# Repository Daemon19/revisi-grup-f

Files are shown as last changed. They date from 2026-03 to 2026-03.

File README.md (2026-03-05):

# 🤖 Revisi Grup F Bayucaraka

Repositori ini berisi hasil pengembangan dan revisi **Final Project Bayucaraka**, yang mencakup tiga bagian utama:

- ⚡ **Electrical**: desain PCB, skematik, dan firmware mikrokontroler.
- 🔧 **Mechanical**: model CAD komponen dan assembly.
- 💻 **Programming**: workspace pemrograman tambahan (MCU/ROS/script).

## 📝 Catatan

- Catatan revisi yang dilakukan dapat ditemukan pada README di masing-masing directory subdivisi
- Folder `Demo` menyimpan versi saat demo.
- Folder `Revisi` adalah hasil perbaikan akhir.

## 🎯 Tujuan Proyek

Proyek ini membangun sistem aktuator berbasis **ESP32** untuk mekanisme pemindahan objek (pick-and-place sederhana), dengan kombinasi:

- 🔀 2 sumbu gerak linear menggunakan motor stepper (X dan Y),
- 🎮 2 servo untuk mekanisme capit dan naik-turun,
- 🏠 limit switch sebagai referensi gerak/home.

## 📁 Struktur Folder Utama

- ⚡ `electrical/`
  - `Demo/`: versi awal desain dan kode.
  - `Revisi/`: versi perbaikan (PCB + firmware final revisi).
    - `CNC V4 Power Jack (PCB)/`: file KiCad (`.kicad_pcb`, `.kicad_sch`, dsb).
    - `FP BAYUCARAKA/`: proyek PlatformIO firmware ESP32.
- 🔧 `mechanical/`
  - `Demo/`: model mekanik sebelum revisi.
  - `Revisi/`: model mekanik setelah revisi.
- 💻 `programming/`
  - `Demo/`: folder pengembangan kode MCU/ROS/script.
  - `Revisi/`: folder lanjutan untuk revisi pemrograman.

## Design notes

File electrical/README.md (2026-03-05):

# ⚡ Revisi Electrical

## 🖨️ PCB

Polaritas kapsitor 100uF pada front.silkscreen terbalik, sehingga dibenarkan di versi revisi

## 💾 KODE

Capit tidak terbuka maksimal sesuai yang dibutuhkan, maka value lebih disesuaikan pada int buka di fungsi `void capit()`.

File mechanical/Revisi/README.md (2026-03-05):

# 🔧 Revisi Mechanical

Bagian-Bagian yang diubah:

- 🏗️ Ground support lebih ringan dengan topologi
- 🦾 Claw lebih kecil dengan akurasi yang relatif sama
- 📉 Hampir semua bagian dibuat lebih kecil / ringan
- 🔄 Penggerak mekanisme lazy tongs di ganti menjadi system pulley, sehingga mekanisme lazy tongs atau linkage hanya memastikan claw dapat naik turun dengan stabil. Dilakukan karena mekanisme sebelumnya mengacaukan Center of Gravity Claw.
- 🎮 Servo di atas menjadi servo 360
- ⚙️ Mounting claw dan mounting atas memiliki 4 lubang total untuk menyeimbangkan claw sehingga claw tidak miring.

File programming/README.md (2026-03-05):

# 💻 Revisi Programming

Adalah hal yang sulit untuk menemukan bug pada proses penggerakan menuju _payload_ tanpa melakukan trial, sehingga bug pada saat demo masih tidak ditemukan.

Meskipun demikian, masih ada ruang untuk mengembangkan basis kode, tepatnya pada node ROS2.
Adapun pengembangannya sebagai berikut.

## 📷 Node Camera

- Kegagalan membuka sumber video akan memunculkan error
- Mempublish koordinat pixel saat file homography tidak ditemukan

## 🎯 Node Detector

- Meningkatkan akurasi deteksi ArUco dengan pengaturan parameter dan preproses

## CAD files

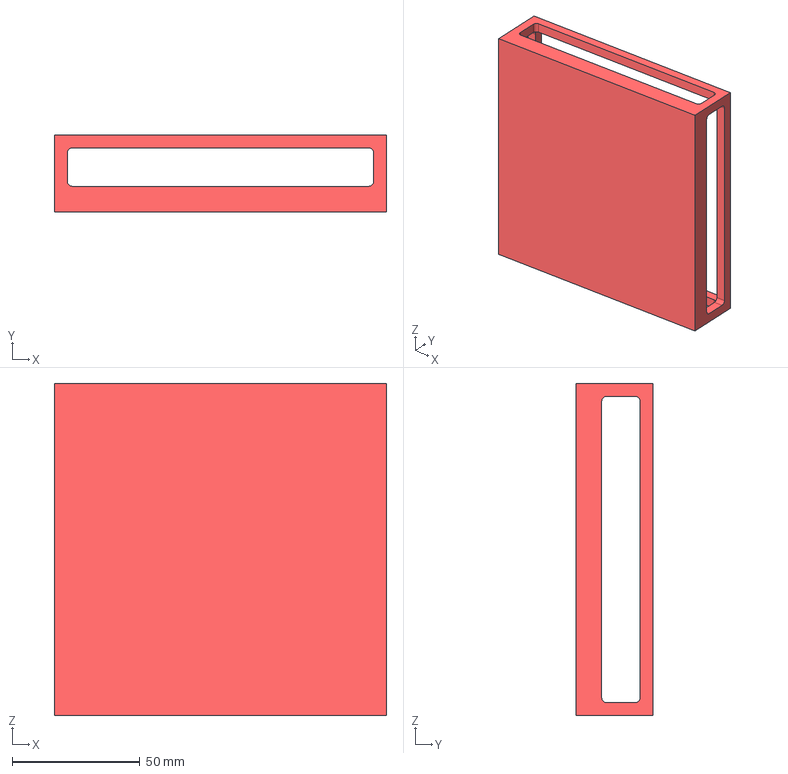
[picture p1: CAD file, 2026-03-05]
mechanical/Demo/Copy of Ground support (Sebelum Revisi).stp
130.0 x 30.0 x 130.0 mm

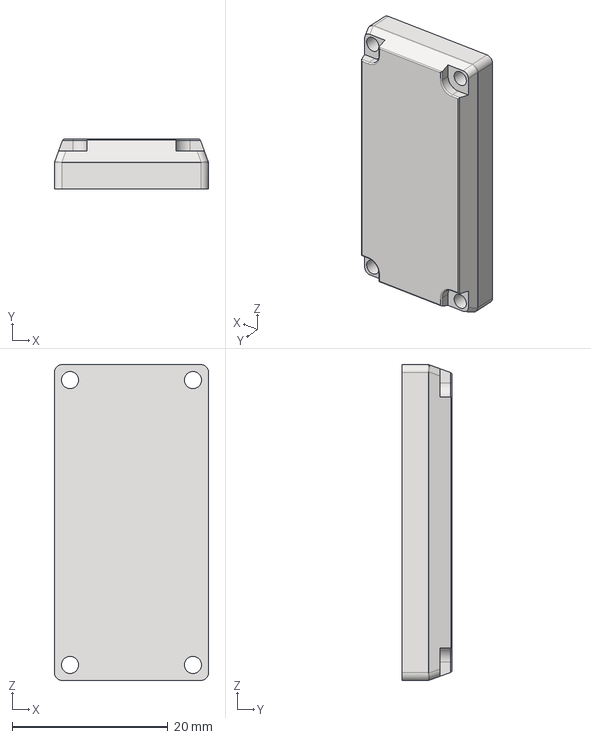
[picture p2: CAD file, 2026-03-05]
mechanical/Demo/FP (Sebelum Revisi)/Base.stp
19.8 x 6.40 x 40.6 mm

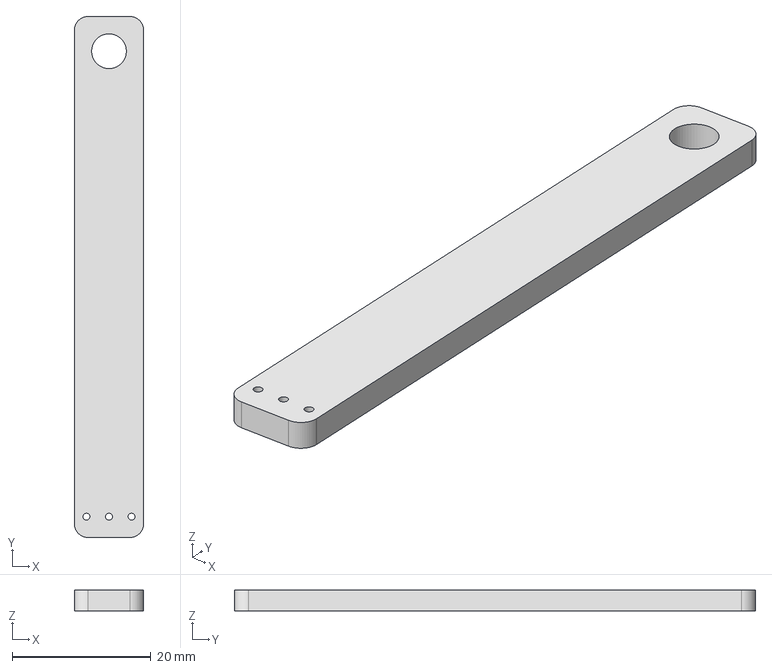
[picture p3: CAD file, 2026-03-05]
mechanical/Demo/FP (Sebelum Revisi)/Servo/FP V2 Servo Arm.stp
10.0 x 75.0 x 3.00 mm

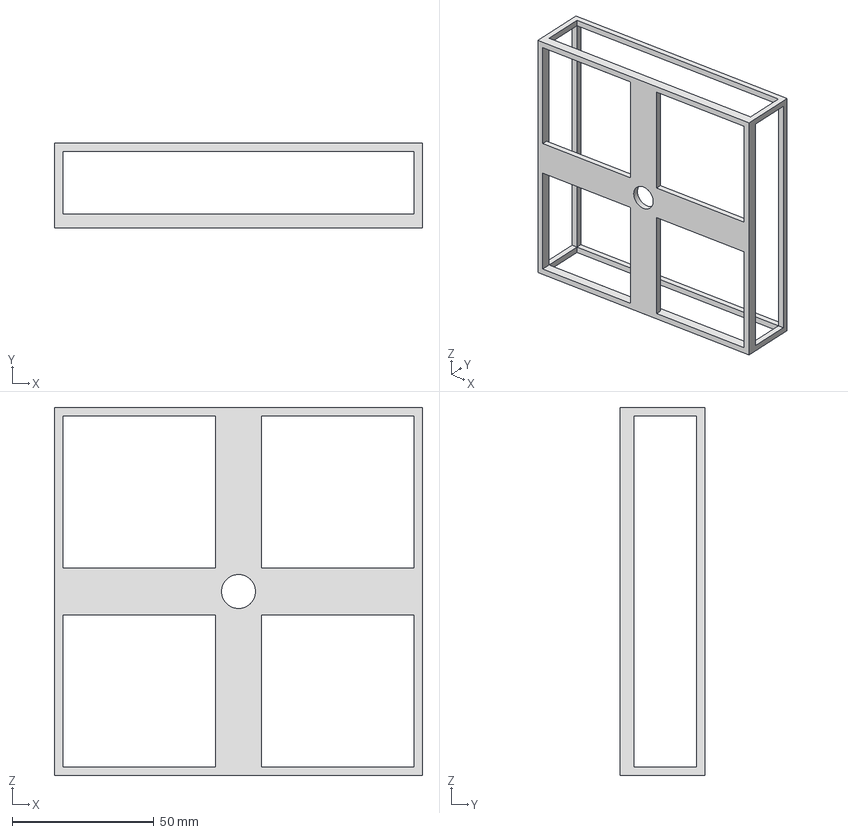
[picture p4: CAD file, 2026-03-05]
mechanical/Revisi/Ground Support (Topologi).stp
130.0 x 30.0 x 130.0 mm

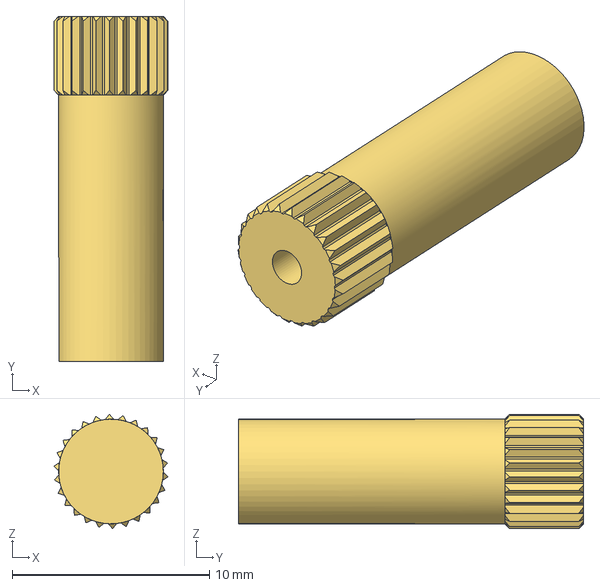
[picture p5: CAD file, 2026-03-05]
mechanical/Demo/FP (Sebelum Revisi)/Eje.stp
5.78 x 17.5 x 5.80 mm

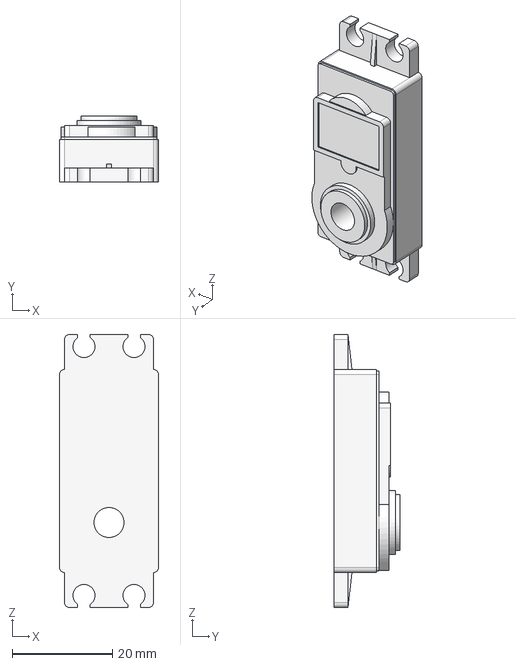
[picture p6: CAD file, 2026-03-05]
mechanical/Demo/FP (Sebelum Revisi)/Servo/Top.stp
19.8 x 13.2 x 54.6 mm

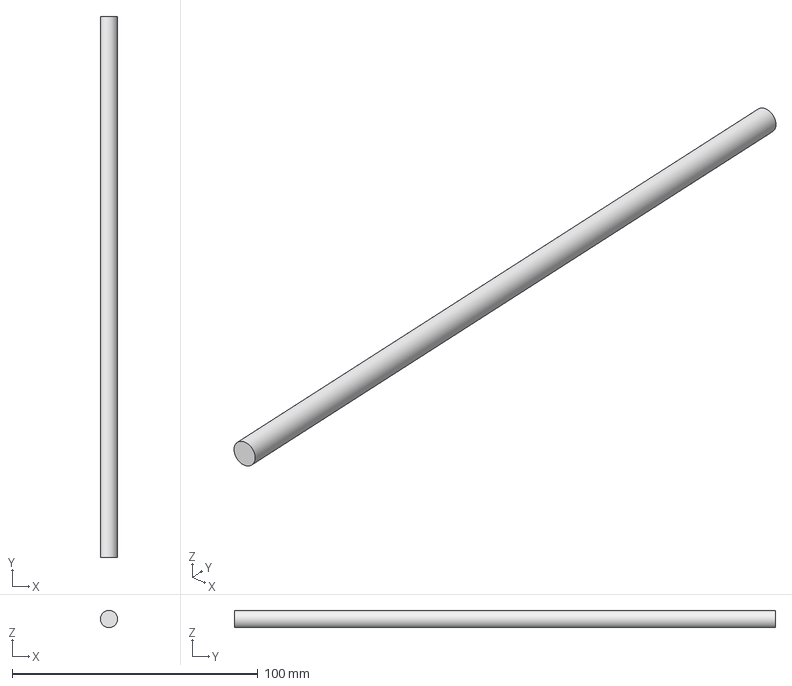
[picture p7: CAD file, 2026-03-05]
mechanical/Demo/FP (Sebelum Revisi)/FP V2 Spring Beam connector.stp
6.99 x 220.0 x 7.00 mm

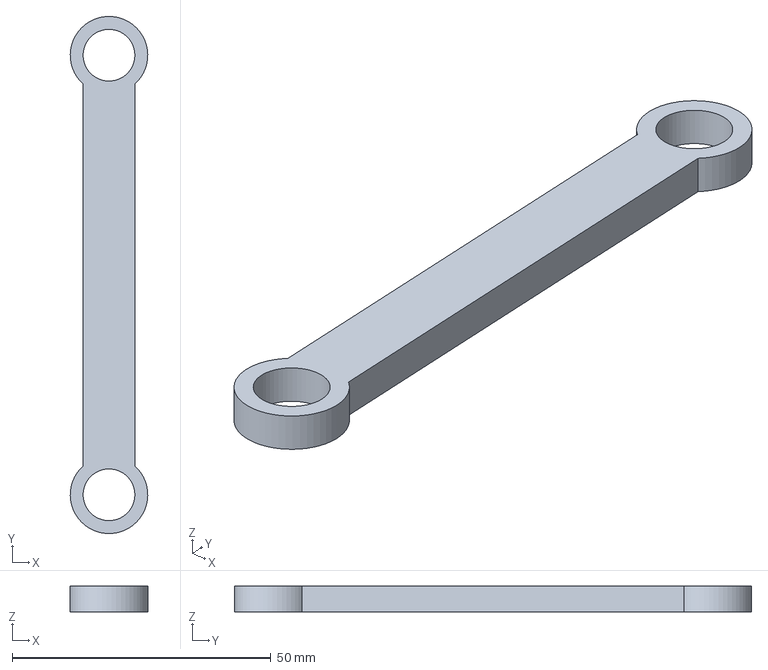
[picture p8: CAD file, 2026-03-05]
mechanical/Demo/FP (Sebelum Revisi)/FP V2 Lengan Serok.stp
15.0 x 100.0 x 5.00 mm

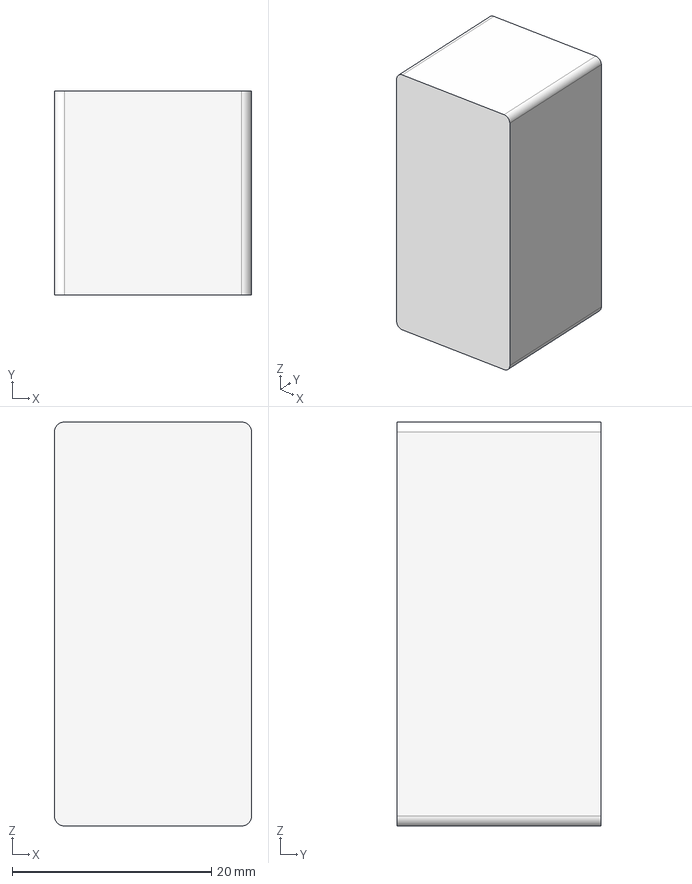
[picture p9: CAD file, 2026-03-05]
mechanical/Demo/FP (Sebelum Revisi)/Medio.stp
19.8 x 20.5 x 40.6 mm

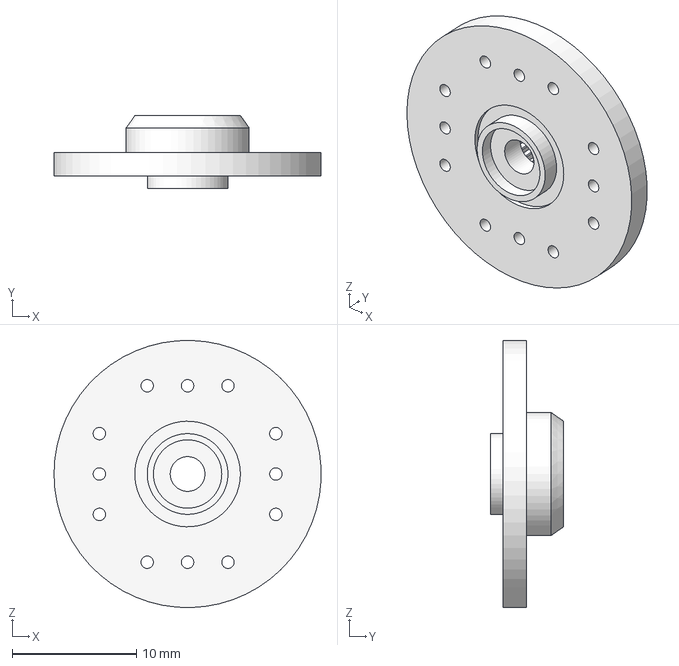
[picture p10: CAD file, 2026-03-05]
mechanical/Demo/FP (Sebelum Revisi)/Servo/Acople circular.stp
21.5 x 5.90 x 21.5 mm

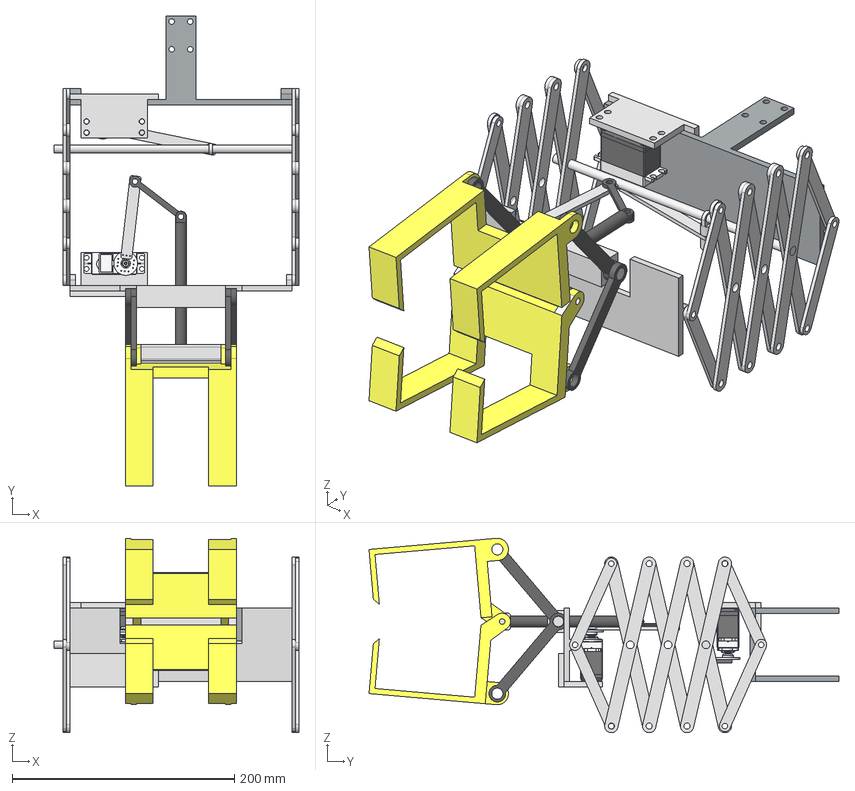
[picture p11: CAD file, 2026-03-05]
mechanical/Demo/FP (Sebelum Revisi)/Final Project Assem.stp
220.0 x 422.8 x 174.9 mm
FP V2 Claw Connector
FP V2 Shaft
FP V2 Arm Connector
FP V2 Mounting Claw
FP V2 Spring beam Short x 8
FP V2 Spring Beam x 12
FP V2 Mounting Plate
FP V2 Z Axis connector
FP V2 Spring Beam connector
fp v2 servo Mounting x 2
Top x 2
Medio x 2
Base x 2
Eje x 2
Acople circular x 2
FP V2 Servo Arm
FP V2 Batang Penggerak
FP V2 Servo Arm v2
FP V2 Claw
FP V2 Claw_Side
FP V2 Lengan Serok x 4

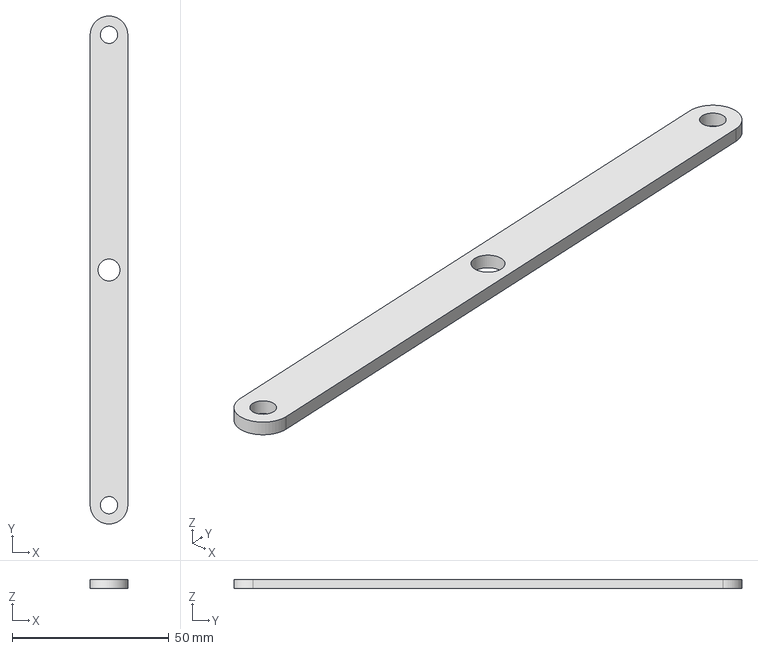
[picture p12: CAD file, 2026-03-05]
mechanical/Demo/FP (Sebelum Revisi)/FP V2 Spring Beam.stp
12.0 x 162.0 x 3.00 mm

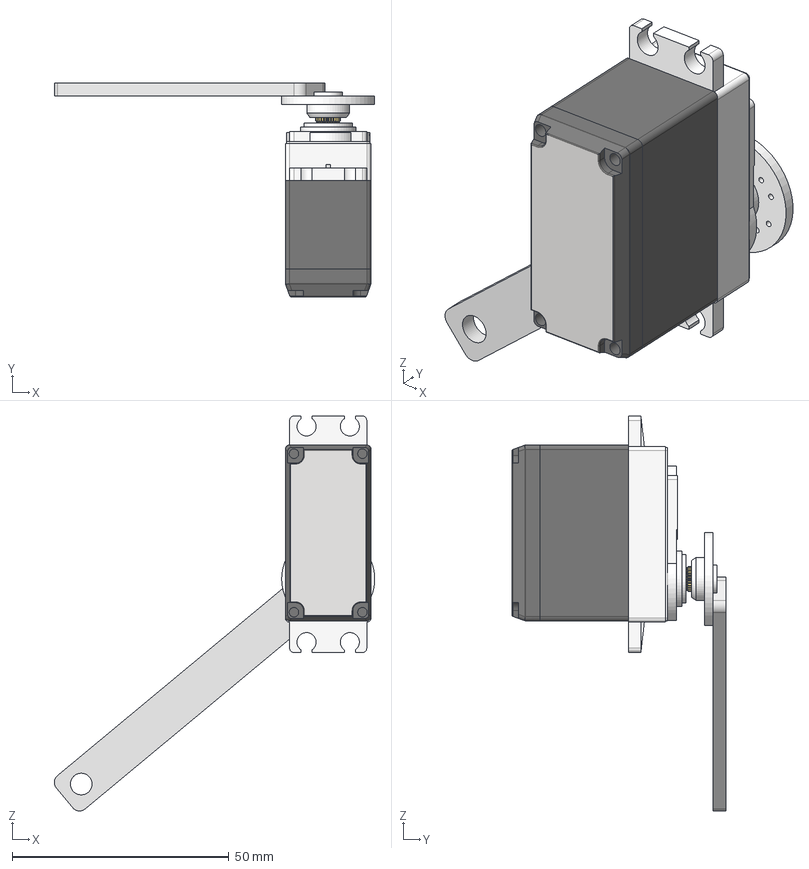
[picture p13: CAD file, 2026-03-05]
mechanical/Demo/FP (Sebelum Revisi)/Servo/MG_996R.stp
74.0 x 49.3 x 91.2 mm
Top
Medio
Base
Eje
Acople circular
FP V2 Servo Arm

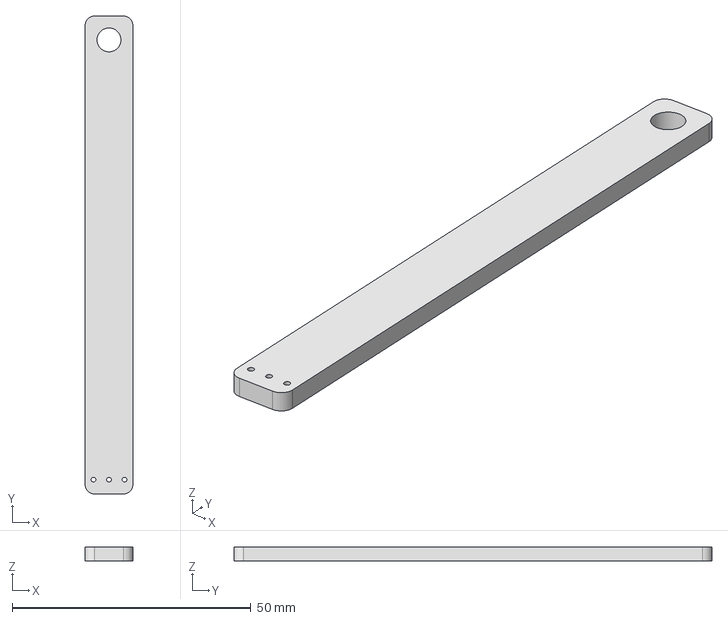
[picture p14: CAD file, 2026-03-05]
mechanical/Demo/FP (Sebelum Revisi)/Servo/FP V2 Servo Arm v2.stp
10.0 x 100.0 x 3.00 mm

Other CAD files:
mechanical/Demo/Copy of Ground Support (Sebelum Revisi).ipt
mechanical/Demo/FP (Sebelum Revisi)/Acople circular.ipt
mechanical/Demo/FP (Sebelum Revisi)/Base.ipt
mechanical/Demo/FP (Sebelum Revisi)/Eje.ipt
mechanical/Demo/FP (Sebelum Revisi)/FP V2 Arm Connector.ipt
mechanical/Demo/FP (Sebelum Revisi)/FP V2 Arm Connector.stp
mechanical/Demo/FP (Sebelum Revisi)/FP V2 Batang Penggerak.ipt
mechanical/Demo/FP (Sebelum Revisi)/FP V2 Batang Penggerak.stp
mechanical/Demo/FP (Sebelum Revisi)/FP V2 Claw Connector.ipt
mechanical/Demo/FP (Sebelum Revisi)/FP V2 Claw Connector.stp
mechanical/Demo/FP (Sebelum Revisi)/FP V2 Claw.ipt
mechanical/Demo/FP (Sebelum Revisi)/FP V2 Claw.stp
mechanical/Demo/FP (Sebelum Revisi)/FP V2 Claw_Side.ipt
mechanical/Demo/FP (Sebelum Revisi)/FP V2 Claw_Side.stp
mechanical/Demo/FP (Sebelum Revisi)/FP V2 Lengan Serok.ipt
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

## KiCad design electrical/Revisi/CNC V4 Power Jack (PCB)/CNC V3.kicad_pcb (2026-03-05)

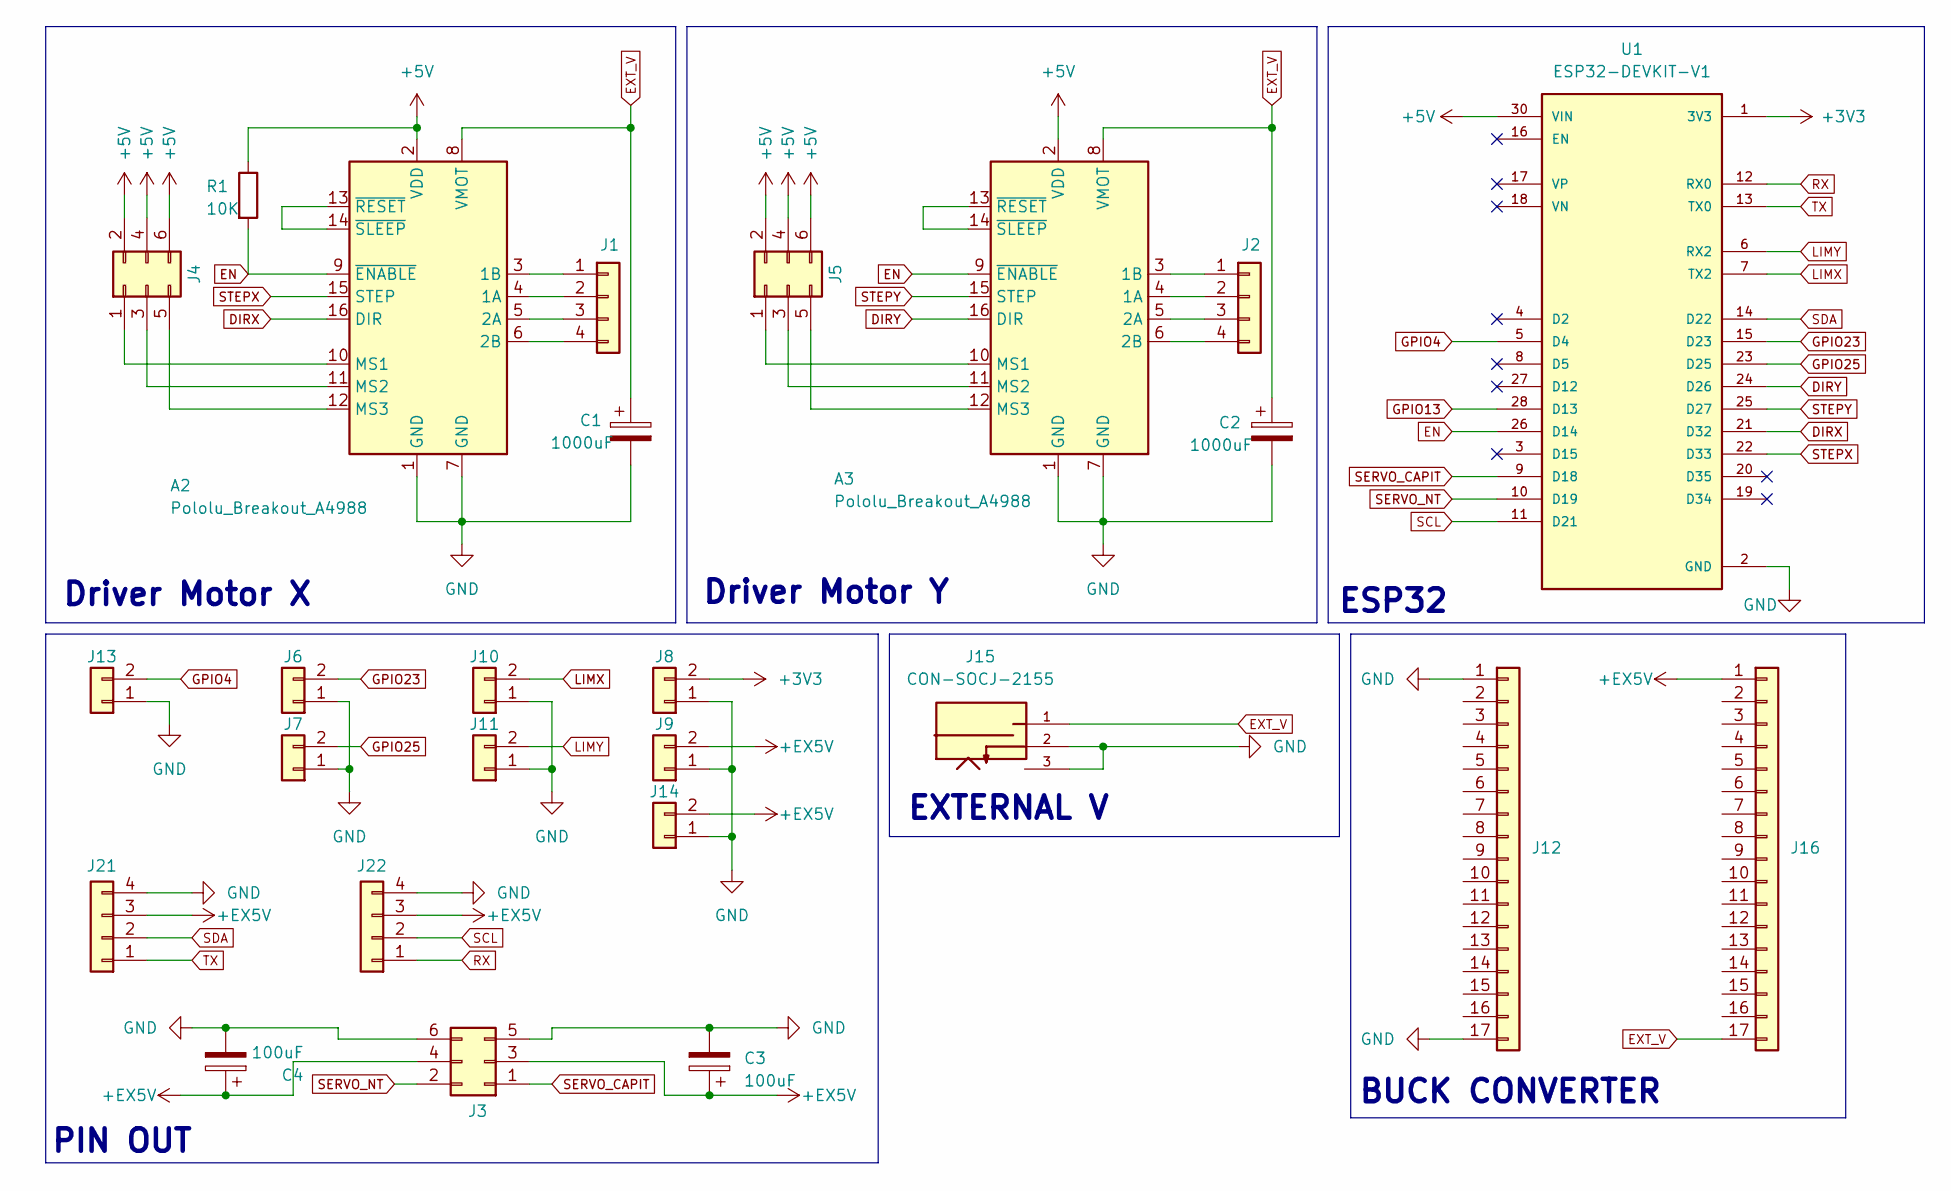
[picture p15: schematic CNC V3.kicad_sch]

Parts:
A2, A3: Pololu_Breakout_A4988; Pololu_Breakout-16_15.2x20.3mm
C1, C2: 1000uF; CP_Radial_D16.0mm_P7.50mm
C3, C4: 100uF; CP_Radial_D8.0mm_P5.00mm
J1, J2, J21, J22: Conn_01x04; PinHeader_1x04_P2.54mm_Vertical
J3, J4, J5: Conn_02x03_Odd_Even; PinHeader_2x03_P2.54mm_Vertical
J6, J7, J8, J9, J10, J11, J13, J14: Conn_01x02; PinHeader_1x02_P2.54mm_Vertical
J12, J16: Conn_01x17; PinSocket_1x17_P2.54mm_Vertical
J15: CON-SOCJ-2155; GRAVITECH_CON-SOCJ-2155; PARTREV NA
R1: 10K; R_Axial_DIN0207_L6.3mm_D2.5mm_P10.16mm_Horizontal
U1: ESP32-DEVKIT-V1; MODULE_ESP32_DEVKIT_V1; PARTREV N/A

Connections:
+3V3: J8.2, U1.1 (3V3)
+5V: A2.2 (VDD), A3.2 (VDD), J4.2, J4.4, J4.6, J5.2, J5.4, J5.6, R1.1, U1.30 (VIN)
+EX5V: C3.1, C4.1, J3.3, J3.4, J9.2, J14.2, J16.1, J21.3, J22.3
DIRX: A2.16 (DIR), U1.21 (D32)
DIRY: A3.16 (DIR), U1.24 (D26)
EN: A2.9 (~ENABLE), A3.9 (~ENABLE), R1.2, U1.26 (D14)
EXT_V: A2.8 (VMOT), A3.8 (VMOT), C1.1, C2.1, J15.1, J16.17
GND: A2.1 (GND), A2.7 (GND), A3.1 (GND), A3.7 (GND), C1.2, C2.2, C3.2, C4.2, J3.5, J3.6, J6.1, J7.1, J8.1, J9.1, J10.1, J11.1, J12.1, J12.17, J13.1, J14.1, J15.2, J15.3, J21.4, J22.4, U1.2 (GND), U1.29 (GND)
GPIO4: J13.2, U1.5 (D4)
GPIO13: U1.28 (D13)
GPIO23: J6.2, U1.15 (D23)
GPIO25: J7.2, U1.23 (D25)
LIMX: J10.2, U1.7 (TX2)
LIMY: J11.2, U1.6 (RX2)
unnamed: A2.4 (1A), J1.2
unnamed: A2.3 (1B), J1.1
unnamed: A2.5 (2A), J1.3
unnamed: A2.6 (2B), J1.4
unnamed: A2.10 (MS1), J4.1
unnamed: A2.11 (MS2), J4.3
unnamed: A2.12 (MS3), J4.5
unnamed: A2.13 (~RESET), A2.14 (~SLEEP)
unnamed: A3.4 (1A), J2.2
unnamed: A3.3 (1B), J2.1
unnamed: A3.5 (2A), J2.3
unnamed: A3.6 (2B), J2.4
unnamed: A3.10 (MS1), J5.1
unnamed: A3.11 (MS2), J5.3
unnamed: A3.12 (MS3), J5.5
unnamed: A3.13 (~RESET), A3.14 (~SLEEP)
RX: J22.1, U1.12 (RX0)
SCL: J22.2, U1.11 (D21)
SDA: J21.2, U1.14 (D22)
SERVO_CAPIT: J3.1, U1.9 (D18)
SERVO_NT: J3.2, U1.10 (D19)
STEPX: A2.15 (STEP), U1.22 (D33)
STEPY: A3.15 (STEP), U1.25 (D27)
TX: J21.1, U1.13 (TX0)

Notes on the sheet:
EXTERNAL V
ESP32
Driver Motor Y
PIN OUT
Driver Motor X
BUCK CONVERTER

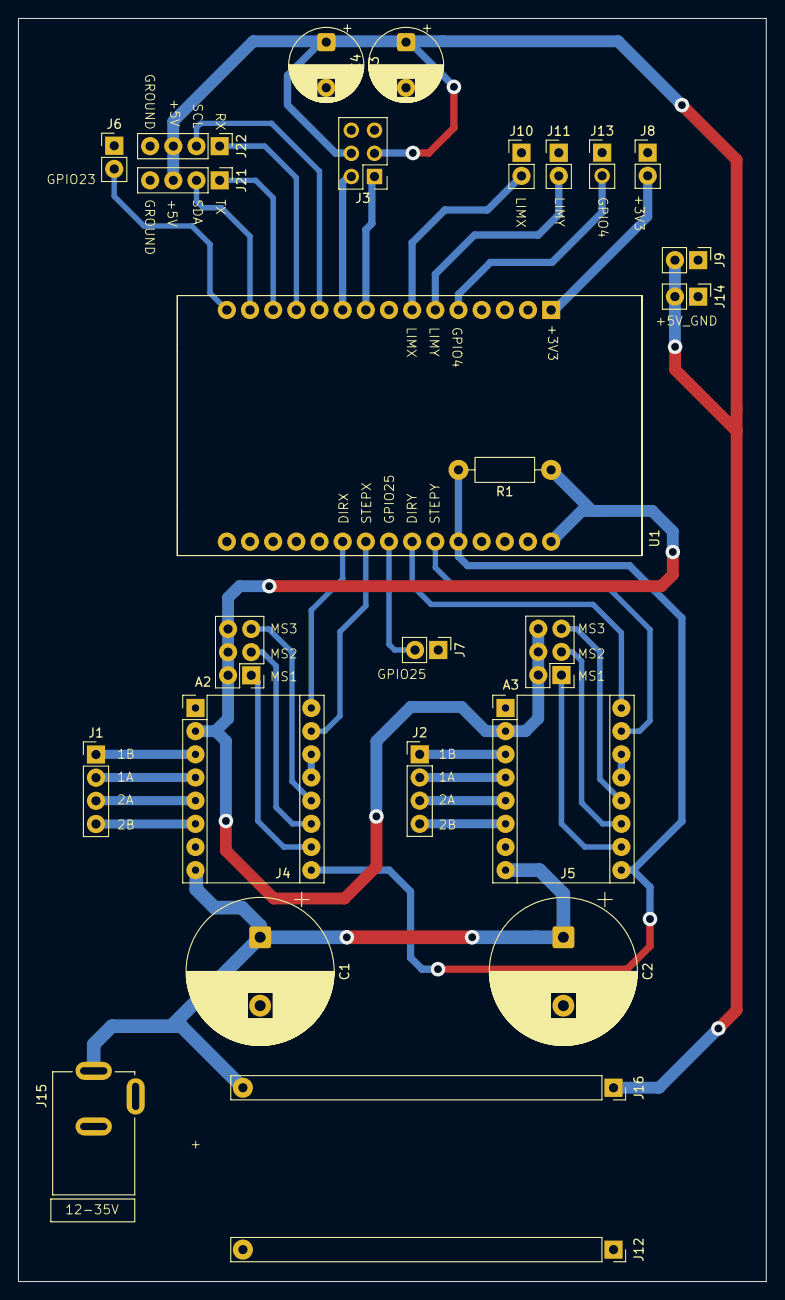
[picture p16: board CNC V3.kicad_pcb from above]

Board: 2 copper layers, 82.0 x 138.5 mm, 26 parts (0 on the bottom side), 37 nets.

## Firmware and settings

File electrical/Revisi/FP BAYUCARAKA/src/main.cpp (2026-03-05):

#include <Arduino.h>
#include <ESP32Servo.h>

#define SERVO_NT 18
#define SERVO_C 19
#define STEPX 33
#define DIRX 32
#define STEPY 27
#define DIRY 26
#define LIMX 16
#define LIMY 17
#define ENABLE 14

void mission(float x_load, float y_load, float x_drop, float y_drop);
void moveToTarget(float x, float y);
void test();
void home();
void capit(bool arah);
void naikturun(bool arah);

Servo servoc;
Servo servont;

const float stepsPerRevolution = 1600;
const float max_x = 41.4;
const float max_y = 45.4;
const float min_arm_x = 0;
const float min_arm_y = 9;
const float max_arm_y = max_y - 9;
const float max_revolution_x = 7;
const float max_revolution_y = 7.275;
const float stepsPercm_x = (stepsPerRevolution * max_revolution_x) / max_x;
const float stepsPercm_y = (stepsPerRevolution * max_revolution_y) / max_y;
float position_x = 0;
float position_y = 9;

void setup() {
  Serial.begin(115200);
  pinMode(ENABLE, OUTPUT);
  pinMode(STEPX, OUTPUT);
  pinMode(DIRX, OUTPUT);
  pinMode(STEPY, OUTPUT);
  pinMode(DIRY, OUTPUT);
  pinMode(LIMX, INPUT_PULLUP);
  pinMode(LIMY, INPUT_PULLUP);
  pinMode(SERVO_C, OUTPUT);
  pinMode(SERVO_NT, OUTPUT);

  digitalWrite(ENABLE, LOW);

  servoc.attach(SERVO_C);
  servont.attach(SERVO_NT);
  servoc.write(100);
  servont.write(140);
}

void loop() {

}

void mission(float x_load, float y_load, float x_drop, float y_drop){
  moveToTarget(x_load, y_load);
  delay(3000);
  naikturun(true);
  delay(3000);
  capit(true);
  delay(3000);
  naikturun(false);
  delay(3000);
  moveToTarget(x_drop, y_drop);
  delay(3000);
  naikturun(true);
  delay(3000);
  capit(false);
  delay(3000);
  naikturun(false);
  delay(3000);
  moveToTarget(0, 0);
  delay(3000);
}

void moveToTarget(float x, float y) {
  float selisih_X = x - position_x;
  float stepsX = abs(selisih_X) * stepsPercm_x;

  digitalWrite(DIRX, selisih_X > 0 ? HIGH : LOW);
  Serial.printf("stepsX: %f\n", stepsX);

  for (int i = 0; i < stepsX; i++) {
    digitalWrite(STEPX, HIGH);
    delayMicroseconds(500);
    digitalWrite(STEPX, LOW);
    delayMicroseconds(500);
  }

  position_x = x;

  float selisih_Y = y - position_y;
  float stepsY = abs(selisih_Y) * stepsPercm_y;

  digitalWrite(DIRY, selisih_Y > 0 ? LOW : HIGH);
  Serial.printf("stepsY: %f\n", stepsY);

  for (int i = 0; i < stepsY; i++) {
    digitalWrite(STEPY, HIGH);
    delayMicroseconds(500);
    digitalWrite(STEPY, LOW);
    delayMicroseconds(500);
  }

  position_y = y;
}

// void test(){
//   digitalWrite(DIRX, HIGH);
//   int stepsX = 0;

//   while(digitalRead(LIMX) != LOW){
//     digitalWrite(STEPX, HIGH);
//     delayMicroseconds(500);
//     digitalWrite(STEPX, LOW);
//     delayMicroseconds(500);
//     stepsX++;
//     Serial.printf("stepsX: %d\n", stepsX);
//   }
  
//   digitalWrite(DIRY, LOW);
//   int stepsY = 0;

//   while(digitalRead(LIMY) != LOW){
//     digitalWrite(STEPY, HIGH);
//     delayMicroseconds(500);
//     digitalWrite(STEPY, LOW);
//     delayMicroseconds(500);
//     stepsY++;
//     Serial.printf("stepsY: %d\n", stepsY);
//   }
// }

// void home(){
//   digitalWrite(DIRX, LOW);

//   while(digitalRead(LIMX) != LOW){
//     digitalWrite(STEPX, HIGH);
//     delayMicroseconds(500);
//     digitalWrite(STEPX, LOW);
//     delayMicroseconds(500);
//   }
  
//   digitalWrite(DIRY, HIGH);

//   while(digitalRead(LIMY) != LOW){
//     digitalWrite(STEPY, HIGH);
//     delayMicroseconds(500);
//     digitalWrite(STEPY, LOW);
//     delayMicroseconds(500);
//   }

//   position_x = 0;
//   position_y = 0;
// }

void capit(bool arah) {
  int buka = 70;
  int tutup = 100;

  if (arah) {
    for (int i = buka; i <= tutup; i++) {
      servoc.write(i);
      delay(10);
    }
    delay(10);
  } else {
    for (int i = tutup; i >= buka; i--) {
      servoc.write(i);
      delay(10);
    }
    delay(10);
  }
}

void naikturun(bool arah) {
  int naik = 100;
  int turun = 80;

  if (arah) {
    for (int i = turun; i < naik; i++) {
      servont.write(i);
      delay(10);
    }
    delay(10);
  } else {
    for (int b = naik; b > turun; b--) {
      servont.write(b);
      delay(10);
    }
    delay(10);
  }
}

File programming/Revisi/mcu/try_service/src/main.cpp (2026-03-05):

#include <Arduino.h>
#include <micro_ros_platformio.h>

#include <rcl/rcl.h>
#include <rclc/rclc.h>
#include <rclc/executor.h>

#include <std_msgs/msg/int32.h>
#include <gantry_interfaces/srv/object_positions.h>

rcl_publisher_t publisher;
std_msgs__msg__Int32 msg;

rcl_service_t service;
gantry_interfaces__srv__ObjectPositions_Request request;
gantry_interfaces__srv__ObjectPositions_Response response;
bool positions_received;

rclc_executor_t executor;
rclc_support_t support;
rcl_allocator_t allocator;
rcl_node_t node;
rcl_timer_t timer;

#define RCCHECK(fn)                \
  {                                \
    rcl_ret_t temp_rc = fn;        \
    if ((temp_rc != RCL_RET_OK)) { \
      error_loop();                \
    }                              \
  }
#define RCSOFTCHECK(fn)            \
  {                                \
    rcl_ret_t temp_rc = fn;        \
    if ((temp_rc != RCL_RET_OK)) { \
      error_loop();                \
    }                              \
  }

// Error handle loop
void error_loop() {
  while (1) {
    delay(100);
    digitalWrite(LED_BUILTIN, !digitalRead(LED_BUILTIN));
  }
}

void timer_callback(rcl_timer_t* timer, int64_t last_call_time) {
  RCLC_UNUSED(last_call_time);
  if (timer != NULL) {
    RCSOFTCHECK(rcl_publish(&publisher, &msg, NULL));
    msg.data++;
  }
}

void mission(float x_payload, float y_payload, float x_dropping_zone,
             float y_dropping_zone) {
  while (1) {
    delay(1000);
    digitalWrite(LED_BUILTIN, !digitalRead(LED_BUILTIN));
  }
}

void object_positions_callback(const void* request_msg, void* response_msg) {
  const gantry_interfaces__srv__ObjectPositions_Request* req =
      (const gantry_interfaces__srv__ObjectPositions_Request*)request_msg;

  positions_received = true;
}

void setup() {
  pinMode(LED_BUILTIN, OUTPUT);

  // Configure serial transport
  Serial.begin(115200);
  set_microros_serial_transports(Serial);
  delay(2000);

  allocator = rcl_get_default_allocator();

  // create init_options
  RCCHECK(rclc_support_init(&support, 0, NULL, &allocator));

  // create node
  RCCHECK(
      rclc_node_init_default(&node, "micro_ros_platformio_node", "", &support));

  RCCHECK(rclc_service_init_default(
      &service, &node,
      ROSIDL_GET_SRV_TYPE_SUPPORT(gantry_interfaces, srv, ObjectPositions),
      "/object_positions"));

  // create publisher
  RCCHECK(rclc_publisher_init_default(
      &publisher, &node, ROSIDL_GET_MSG_TYPE_SUPPORT(std_msgs, msg, Int32),
      "micro_ros_platformio_node_publisher"));

  // create timer,
  const unsigned int timer_timeout = 1000;
  RCCHECK(rclc_timer_init_default(&timer, &support, RCL_MS_TO_NS(timer_timeout),
                                  timer_callback));

  // create executor
  RCCHECK(rclc_executor_init(&executor, &support.context, 2, &allocator));
  RCCHECK(rclc_executor_add_timer(&executor, &timer));
  RCCHECK(rclc_executor_add_service(&executor, &service, &request, &response,
                                    object_positions_callback));

  msg.data = 0;
  positions_received = false;
}

void loop() {
  while (!positions_received) {
    delay(100);
    RCSOFTCHECK(rclc_executor_spin_some(&executor, RCL_MS_TO_NS(100)));
  }
  mission(request.payload.x, request.payload.y, request.dropping_zone.x,
          request.dropping_zone.y);
}
